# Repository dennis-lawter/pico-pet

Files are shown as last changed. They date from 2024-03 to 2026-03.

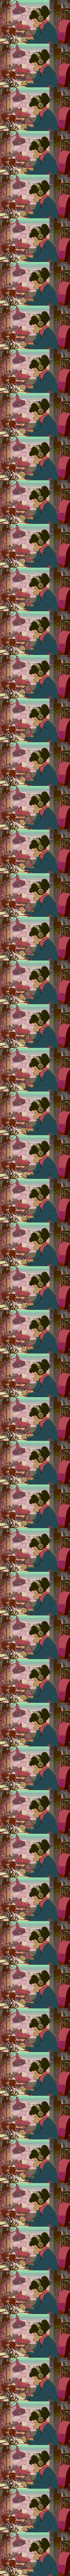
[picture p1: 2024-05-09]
embedded/assets/sprite_png/lofi.png

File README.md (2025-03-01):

# Pico Pet
A virtual pet that requires the user to complete pomodoros for the health of their pet.

## Hardware
- Raspberry Pi Pico
    - [Raspberry Pi Pico](https://www.raspberrypi.com/products/raspberry-pi-pico/) for development
    - [Waveshare RP2040-Tiny](https://www.waveshare.com/rp2040-tiny.htm) for release
- [Waveshare 1.44" LCD](https://www.waveshare.com/pico-lcd-1.44.htm)
- [DS3231](https://www.amazon.com/dp/B09KPC8JZQ/)
- Any 5v to 3v3 shifter for the DS3231, [for example](https://www.amazon.com/dp/B07LG646VS/)
- Any 5v speaker or buzzer, [for example](https://www.amazon.com/dp/B07P6X9YX7/)
- Any 3v-5v vibrating motor, [for example](https://www.amazon.com/dp/B073YFR5WR)

## NVM Utilization
The NVM (Non-Volatile Memory) module included with the DS3231 provides 4KiB arranged in 512 pages of 8 bytes each.

Permanent storage must be serializable to a specified number of pages, and write to an assigned page address.

Pages are addressed from hexidecimal 0x000 to 0x1ff.

| Page Start | Page End | Module |
| --- | --- | --- |
| 000 | 000 | Header |
| 001 | 002 | Settings |
| 003 | 003 | Inventory |
| 004 | 005 | Pet |

*note: If the NVM becomes corrupted, try changing the const `NVM_SENTINEL` to force a header guard check failure. This will factory reset the device, and all data will be lost.*
|  | **Header** |
| --- | --- |
| 0 | if set to the `NVM_SENTINEL` value, then the EEPROM is assumed to contain a valid savefile |
| 1 |  |
| 2 |  |
| 3 |  |
| 4 |  |
| 5 |  |
| 6 |  |
| 7 |  |

|  | **Settings Page 1** | min | max |
| --- | --- | --- | --- |
| 0 | User brightness | 0 | 15 |
| 1 | User volume | 0 | 4 |
| 2 | *nyi* Vibration enabled | 0 | 1 |
| 3 | *nyi* 12hr clock enabled | 0 | 1 |
| 4 | *nyi* minutes before device sleeps | 1 | 90 |
| 5 |  |  |  |
| 6 |  |  |  |
| 7 |  |  |  |

|  | **Settings Page 2** | min | max |
| --- | --- | --- | --- |
| 0 | Pomodoro length in minutes | 1 | 90 |
| 1 | Short break length in minutes | 1 | 90 |
| 2 | Long break length in minutes | 1 | 90 |
| 3 | Cycles, aka number of pomodoros before a long rest | 1 | 9 |
| 4 | Pet feeding deadline hr | 0 | 23 |
| 5 | Pet feeding deadline min | 0 | 59 |
| 6 |  |  |  |
| 7 |  |  |  |

|  | **Inventory** | min | max |
| --- | --- | --- | --- |
| 0 | Tomatoes | 0 | 99 |
| 1 | Raspberries | 0 | 9 |
| 2 | Lower byte of juice value |  |  |
| 3 | Higher byte of juice value |  |  |
| 4 |  |  |  |
| 5 |  |  |  |
| 6 |  |  |  |
| 7 |  |  |  |

Max juice is 9999ml as a u16

|  | **Pet Page 1** |
| --- | --- |
| 0 | Birth Day |
| 1 | Birth Month |
| 2 | Birth Year |
| 3 |  |
| 4 |  |
| 5 |  |
| 6 |  |
| 7 |  |

|  | **Pet Page 2** |
| --- | --- |
| 0 | Current HP |
| 1 | Sickness |
| 2 | Daily Hunger |
| 3 | Last Fed Day |
| 4 | Last Fed Month |
| 5 | Last Fed Year |
| 6 |  |
| 7 |  |

Max HP = Daily Hunger + 4

Last Fed Year is probably excessive,
but it'd be a weird bug if someone started the pet up after exactly 1 year,
and their pet showed no signs of missed days of hunger...

## Pin Out For Raspberry Pico

```mermaid
graph LR
    subgraph RP2040
        Pin1
        Pin2
        %%Pin3[GND]
        Pin4
        Pin5
        Pin6
        Pin7
        %%Pin8[GND]
        Pin9
        %%Pin10
        Pin11
        Pin12
        %%Pin13[GND]
        Pin14
        Pin15
        Pin16
        Pin17
        %%Pin18[GND]
        %%Pin19
        Pin20
        %%Pin21
        Pin22
        %%Pin23[GND]
        %%Pin24
        %%Pin25
        %%Pin26
        %%Pin27
        %%Pin28[GND]
        %%Pin29
        %%Pin30
        %%Pin31
        %%Pin32
        %%Pin33[GND]
        %%Pin34
        %%Pin35
        %%Pin36[3V3_OUT]
        %%Pin37[3V3_EN]
        %%Pin38[GND]
        %%Pin39[VSYS]
        %%Pin40[VBUS]
    end

    subgraph RTC_NVM
        RTC_SDA
        RTC_SCL
        RTC_SQW
    end
    Pin1[Pin1 I2C0_SDA] --> RTC_SDA
    Pin2[Pin2 I2C0_SCL] --> RTC_SCL
    Pin7[Pin7 GP5] --> RTC_SQW

    subgraph BUZZER
        SPEAKER
    end
    Pin6[Pin6 PWM_A2] --> SPEAKER

    subgraph VIBRATION
        MOTOR
    end
    Pin9[Pin9 GP6] --> MOTOR

    subgraph LCD
        LCD_KEY2
        LCD_KEY3
        LCD_DC
        LCD_CS
        LCD_CLK
        LCD_DIN
        LCD_RST
        LCD_BL
        LCD_KEY0
        LCD_KEY1
    end
    Pin4[Pin4 GP2] --> LCD_KEY2
    Pin5[Pin5 GP3] --> LCD_KEY3
    Pin11[Pin11 GP8] --> LCD_DC
    Pin12[Pin12 SPI1_CSn] --> LCD_CS
    Pin14[Pin14 SPI1_SCK] --> LCD_CLK
    Pin15[Pin15 SPI1_TX] --> LCD_DIN
    Pin16[Pin16 SPI1_RX] --> LCD_RST
    Pin17[Pin17 PWM_B6] --> LCD_BL
    Pin20[Pin20 GP15] --> LCD_KEY0
    Pin22[Pin22 GP17] --> LCD_KEY1
```

## Pinout for Waveshare RP2040-Tiny
```mermaid
graph LR
    subgraph RP2040-Tiny
        TinyPin0
        TinyPin1
        TinyPin2
        TinyPin3
        TinyPin4
        TinyPin5
        TinyPin6
        %%TinyPin7
        TinyPin8
        TinyPin9
        TinyPin10
        TinyPin11
        TinyPin12
        TinyPin13
        %%TinyPin14
        TinyPin15
        %%TinyPin16
        %%TinyPin17
        %%TinyPin18
        TinyPin19
        %%TinyPin20
        %%TinyPin21[3V3]
        %%TinyPin22[GND]
        %%TinyPin23[5V]
    end

    subgraph RTC_NVM
        RTC_SDA
        RTC_SCL
        RTC_SQW
    end
    TinyPin0[TinyPin0 I2C0_SDA] --> RTC_SDA
    TinyPin1[TinyPin1 I2C0_SCL] --> RTC_SCL
    TinyPin5[TinyPin5 GP5] --> RTC_SQW

    subgraph BUZZER
        SPEAKER
    end
    TinyPin4[TinyPin4 PWM_A2] --> SPEAKER

    subgraph VIBRATION
        MOTOR
    end
    TinyPin6[TinyPin6 GP6] --> MOTOR

    subgraph LCD
        LCD_KEY2
        LCD_KEY3
        LCD_DC
        LCD_CS
        LCD_CLK
        LCD_DIN
        LCD_RST
        LCD_BL
        LCD_KEY0
        LCD_KEY1
    end
    TinyPin2[TinyPin2 GP2] --> LCD_KEY2
    TinyPin3[TinyPin3 GP3] --> LCD_KEY3
    TinyPin8[TinyPin8 GP8] --> LCD_DC
    TinyPin9[TinyPin9 SPI1_CSn] --> LCD_CS
    TinyPin10[TinyPin10 SPI1_SCK] --> LCD_CLK
    TinyPin11[TinyPin11 SPI1_TX] --> LCD_DIN
    TinyPin12[TinyPin12 SPI1_RX] --> LCD_RST
    TinyPin13[TinyPin13 PWM_B6] --> LCD_BL
    TinyPin15[TinyPin15 GP15] --> LCD_KEY0
    TinyPin19[TinyPin19 GP29] --> LCD_KEY1
```

## Development Breakboard Build
Below are my recommendations for how to build the development board.

### Shopping List
All amazon links are tracking free and affiliate free; feel free to source these where you wish, but compatability is not guaranteed for other similar products.
The current iteration of the software is absolutely tied to the LCD module below, as well as the combination DS3231 & AT24C32 board.
Theoretically any RTC and NVM module could replace the aformentioned, but the I2C addresses have been set to match the product below.
Additionally, any ST7735S driven 128x128 display could be adapted. All four buttons provided on the waveshare LCD hat are used as well.
- Components
    - Expansion Board https://www.amazon.com/dp/B08X6FPRYF/
    - Breakout Board https://www.amazon.com/dp/B0B982B9HV/
    - Breadboard https://www.amazon.com/dp/B07VFFXPH3/
    - LCD Module https://www.amazon.com/dp/B0957NJP97/
    - Raspberry Pico w/ presoldered headers https://www.amazon.com/dp/B08X7HN2VG/
    - RTC Board https://www.amazon.com/dp/B09KPC8JZQ/
    - Vibrating Motor https://www.amazon.com/dp/B073YFR5WR/
    - Piezo Buzzer https://www.amazon.com/dp/B07P6X9YX7/
- Tools/Resources
    - 22 AWG solid hookup wire https://www.amazon.com/dp/B07TX6BX47/
    - 22 AWG wire stripper https://www.amazon.com/dp/B06X9875Z7/
    - CR2032 battery https://www.amazon.com/dp/B071D4DKTZ/
    - Command strip https://www.amazon.com/dp/B07P32RHQ4/

### Assembly
1. Socket the Raspberry Pico into center of the Expansion Board.
2. Socket the LCD Module into the left slot of the Expansion Board.
3. Using a command strip, attach the breadboard to the flat side of the breakout board.
    - The 1A point of the breadboard should be in the top left, near where the word VBUS is printed on the back of the breakout board.
    - While many breadboards do come with stickers, there is often no solid insulating layer for the conductive rails, and the breakout board has sharp solder points that can stab through this thin soft layer. Whatever you do, I recommend insulating these two boards or you will risk a short...
4. Connect the breakout terminal VSYS and tie point 1A on the breadboard, preferably using a red wire.
    - I recommend running this wire over the top of the board rather than the side as it would be natural to do, because there will be essentially no space between the Raspberry Pico and this specific Breakout Board when they are eventually mated.
5. Connect the breakout terminal GND (the one adjacent to VSYS) and tie point 2A on the breadboard, preferably using a black wire.
    - Again, I recommend running this wire over the top of the board.
6. Connect the data lines to the breadboard, this time allowing the wires to wrap around the side of the board (recommended colors in parenthesis):
    - GP0 to J1 (green)
    - GP1 to J2 (white)
    - GP4 to J5 (yellow)
    - GP5 to J6 (blue)
    - GP6 to J7 (green)
7. Connect new lines on the breadboard for the RTC module:
    - C2 to C3 (black)
    - D1 to D4 (red)
    - H1 to B5 (green)
    - H2 to B6 (white)
    - H6 to B7 (blue) (I recommend routing this cable up then following the other 2 data lines)
8. Connect new lines on the breadboard for the piezo buzzer:
    - G5 to F17 (orange)
    - E2 to G13 (black) (I recommend routing this along the top side, then down the gap I left in the I column)
9. Connect new lines on the breadboard for the vibration motor:
    - G7 to K16 (green)
    - F13 to F15 (black)
10. Stick the vibration motor onto the bottom of the breadboard.
11. Attach the vibration motor wires (letting the wires lay to the right):
    - red wire to G16
    - blue wire to G15
12. Place the piezo buzzer onto pins J17 and J13 (placement will secure the vibration motor wires)
13. Insert a CR2032 battery into the RTC module.
14. Place the RTC module onto pins A3, A4, A5, A6, A7, and A8.
15. Finally, socket the breakout board onto the right slot of the Expansion Board.

### Development Environment Setup
#### NixOS
I recommend running the following to open the VSCodium development environment:
```bash
nix develop --command codium .
```

You can of course just use whatever text editor you like, and simply enter the flake in a terminal with:
```bash
nix develop
```

#### Other Linux Distros
You'll need Rust installed and set to nightly-2023-11-16. Other versions may not be supported. You will likely also need udev to detect the raspberry pico. To use the makefile, you'll also want gnu make. You can review the `flake.nix` and attempt to reproduce it in your own OS.

### First Time Setup
Your first time opening this repo, you'll need to setup the dependencies and enable the thumbv6m-none-eabi target. This has been automated for you:
```bash
make init
```

### Running The Code
The build process performs a number of actions. The sprites will be converted from PNG files to raw binary files containing RGB332 data. Fonts will be converted from PNG files to binary files containg black&white data. The custom PEAT audio files will be converted from plaintext files to the binary custom BEAT format. With all assets converted, the project will finally build and attempt to upload.

All of this is as simple as invoking:
```bash
make run
```

## Attributions
Placeholder artwork (lofi.png) copyright belongs to Juan Pablo Machado.

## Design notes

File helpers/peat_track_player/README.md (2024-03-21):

# PEAT File Format
**PEAT** stands for Plaintext Embedded Audio Track.

## Purpose
The purpose of this file is to encode a track played on a single channel with single notes played in sequence.
These files are able to encode audio in a very small format for embedded hardware.

## Driver
The audio driver supports 1,256 notes per minute (NPM).
Files may compress their notes significantly by using an integer note per minute divisor (NPMD).
NPMD must be between 1 and 255.

## Example File
For an example PEAT file, this is the classic Take Me Out To The Ball Game.
- The composition is in C Major.
- The time signature is in 3/4.
- With an NPMD of 2, the hardware plays 628 notes per minute.
- Each note, in this PEAT file, is representative of a 16th note.
- To encode a fully voiced quarter note with these settings, you could do: `C4 . . .`.
- Each note is purposefully ended with a 16th note rest.
- Ending notes with a single note of rest is useful when the song has repeated notes.
- Repeated notes will sustain; later in this song there are repeated notes.
- While those notes could have been separated with 16th note rests, I decided to place a rest after every note.
- This was not the only solution to the problem, feel free to experiment.

| File | Explanation |
| --- | --- |
| `PEAT 1` | *REQUIRED* Version identifier. |
| `NPMD 2` | *REQUIRED* NPMD signifier, must be 1-255. |
| `Take Me Out To The Ball Game` | *REQUIRED* Song title, only displayed in PEAT player. |
|  | *REQUIRED* Header ends with a blank line. |
| `C4  . . . . . . _` | Play a C4 for 7 notes, then rest for 1 note. |
| `C5  . . _` | Play a C5 for 3 notes, then rest for 1 note. |
| `A4  . . _` | The period is a "sustain" indicator. |
| `G4  . . _` | Without the rest, the notes would transition with no interruption. |
| `F4  . . _` | On the embedded hardware, there should be no interruption between these 3 F4 notes |
| `G4  . . . . . . . . . . _` | This G4 plays for an entire "measure" by lasting 15 notes + a rest |

## Important notes
The notes provided must lie between C4 and C7.

The voicing is always a square wave.

You may use the following to represent a C#4 note:
- `C#4`
- `Cs4`
- `Db4`

You may use `.` to "sustain" a note for an additional note.

The `_` note represents a rest.

Notes must be separated by at least one character whitespace(spaces, tabs, newlines).

There are no chords; the hardware can play at most one note at any given time.

Without a rest, there is no distinction between repeated notes.

Repeated notes are identical to a sustain.

That is to say, that these are all identical ways to represent the same wave format:
- `C4 C4 C4 C4`
- `C4 . . .`
- `C4 . C4 .`

# BEAT File Format
The purpose of a **PEAT** file is to compile into a **BEAT** (Binary Embedded Audio Track) file.

The first byte of a BEAT file is the NPMD, and the byte must be between `0x01` and `0xFF`.

Every byte after that represents the song.

A4 (440hz) has been chosen as the byte `0x80`.

Every half-step up from A4 is an increase of that base byte by 1.

Every half-step down from A4 is a decrease of that base byte by 1.

The byte `0x00` represents a rest.

There is no idea of "sustain", instead repeated notes are assumed to be a continued note.

The following is an example BEAT file, represented in hex, from the previous snippet of Take Me Out To The Ball Game.

```beat
02 77 77 77 77 77 77 77
00 83 83 83 00 80 80 80
00 7E 7E 7E 00 7C 7C 7C
00 7E 7E 7E 7E 7E 7E 7E
00
```

Here, the first byte is `0x02` representing the NPMD.

Then, seven `0x77` bytes and a `0x00` byte follow, representing the above `C4 . . . . . . _`

The song continues from there, each byte representing the note from the PEAT file.

It's worth noting that because of the single byte at the beginning of the file,
and our typical conventions of music revolving around groups of 4 notes,
it is very common that a file will be an odd number of bytes.

The entire Take Me Out To The Ball Game BEAT file is 397 bytes,
including the 12 continuous rests at the end used for resting before the track loops in another application.

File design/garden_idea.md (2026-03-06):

# Town concept
Pets live in a 7x7 garden

┌───┬───┬───┬───┬───┬───┬───┐
│   │   │   │   │   │   │   │
├───┼───┼───┼───┼───┼───┼───┤
│   │   │   │   │   │   │   │
├───┼───┼───┼───┼───┼───┼───┤
│   │   │   │   │   │   │   │
├───┼───┼───┼───┼───┼───┼───┤
│   │   │   │ H │   │   │   │
├───┼───┼───┼───┼───┼───┼───┤
│   │   │   │   │   │   │   │
├───┼───┼───┼───┼───┼───┼───┤
│   │   │   │   │   │   │   │
├───┼───┼───┼───┼───┼───┼───┤
│   │   │   │   │   │   │   │
└───┴───┴───┴───┴───┴───┴───┘

Every day you should water a tile.
Whichever tile is the best (or latest if tied) watered will spawn a new pet.

## End of week
Every end of the week, there's an alert to view your report card.
If the pet sleeps without showing the report card,
reduce happiness by 1 for all pets,
then do the check.

In the report card:
You'll see total pomos, breaks, etc.
You'll see the watering results.

Check if any pets are older than their expected lifespan.
Kill off the oldest pet who is past their prime.
Show the user which one died.

Check if any pets are at 0 happiness.
If so, they die.

Now, if the user got at least 75% of their pomos compared to their expected...
And if the 20 pet limit is not currently met...
Sort all the plots based on water level.
Sub-sort them based on most recent watering.
At this best watered spot, spawn a new pet.

# What stats does a pet have?
Happiness: 0-16 4b
X: 0-7 3b
Y: 0-7 3b
Age (days): 0-255 8b

# What stats does the town have?
Hunger (calculated)
Hunger rate (calculated)
Expected pomos for the week: 0-255 8b
DateTime of last feeding u32
Hunger at last feeding u32?
Currently stored food: 0-65,535 u16
First day of week: 0-7 3b
Days left in tutorial mode: 0-16 4b
DateTime of last save u32

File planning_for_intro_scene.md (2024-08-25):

fade in from black to white

# System Setup
Before we begin, let's adjust a few things. If you need to go back to a previous page, hold the BACK button.

`brightness entry`

`volume entry`

`vibration entry`

`Confirm`

# Welcome
<!-- Introduce pet -->

# Setup
Please enter today's date

`date selector`

`Confirm`

# Setup
Please enter the current time

`AM/PM selector`

`time selector`

`Confirm`

# Pet Nutrition
<!-- Explain pet nutrition -->

# Setup
What would be a good time to feed your pet? If you fail to feed the pet by the deadline, your pet may get sick!

`feed time selector`

`Confirm`

# About Pomodoro
<!-- Explain pomodoro -->

# Setup
Cycles are important for obtaining raspberries. How many cycles should a full pomodoro cycle contain?

`cycle entry`

`Confirm`

# Setup
How long would you like your work session to be? (recommended: 25m)

`pomo time entry`

`Confirm`

How long would you like your short rest to be? (recommended: 5m)

`short rest entry`

`Confirm`

How long would you like your long rest to be? (recommended: 15m)

`long rest entry`

`Confirm`

# Ready?
That wraps it up! You can change any of these settings later.

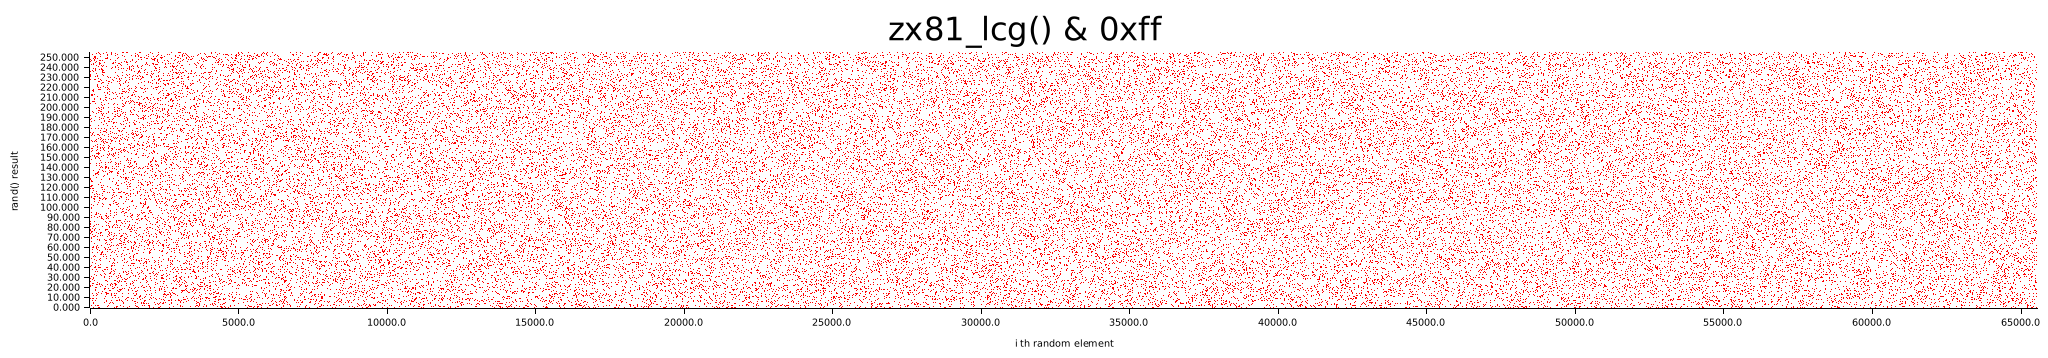
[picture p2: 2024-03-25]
helpers/rng-plotter/output.png

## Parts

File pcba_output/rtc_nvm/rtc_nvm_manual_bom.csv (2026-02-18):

Comment | Designator | Footprint | LCSC Part Number
4.7uF | C1 | 0805 | C1779
CR1225 Battery Clip | J1 |  | C20606803
5P 2.54mm Header Pins | J2 |  | C5156614
5.1k ohm | R1,R2,R3 | 0402 | C22356228
DS3231M I2C RTC | U1 | SOIC-8_3.9x4.9mm | C107410
AT24CS32 I2C NVM | U2 | SOIC-8_3.9x5.4mm | C615972

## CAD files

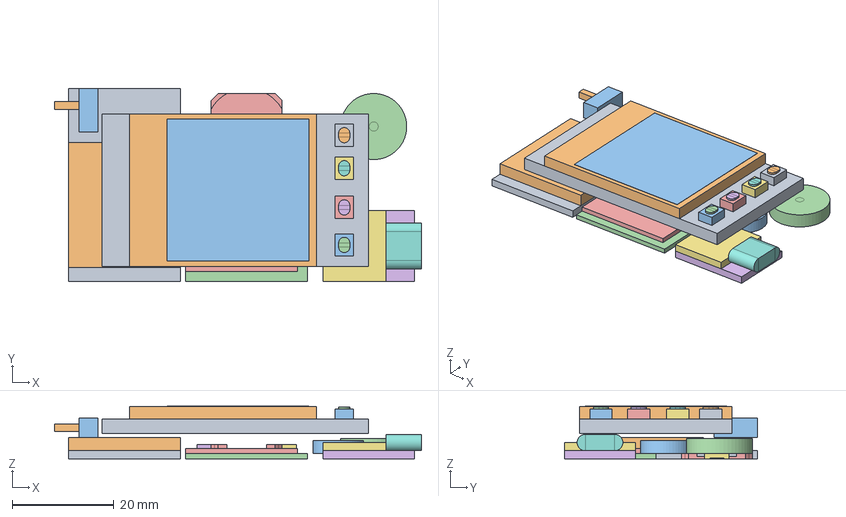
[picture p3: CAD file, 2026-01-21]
freecad/picopet.FCStd
72.2 x 38.0 x 10.4 mm
BoardAndSmds
ScreenHousing
Base
Rubber
Base001
Rubber001
Base002
Rubber002
Base003
Rubber003
Display
Board
Components
Board001
Components001
USBC
Board002
Components002
Pole

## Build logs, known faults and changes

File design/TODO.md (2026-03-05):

# Design
- TODO: list

# Hardware
## USB board
- Finalize circuit
- Upload to circuit fab and customize
- Order circuit
- Receive modules
- Solder headers to a test board
- Confirm function w/ dev board
## MCU board
- TODO: list

# Software
- TODO: list

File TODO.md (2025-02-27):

# TODO

This list is not final. It will grow and evolve.

Done items should be removed from the list.

- Misc
  - When adjusting date/time, there needs to be adjustments made to the feeding schedule
  - Warn users when adjusting date/time that feeding schedule may be affected (maybe unnecessary?)
  - Idle setting, how many minutes
  - Store the `MainScene::menu_item_selected` as a static/global for reloading the scene
  - Handle AM/PM time adjustment in settings scene
- Intro Scene
  - Introduce pet
  - Explain the pomodoro method
  - Explain how feeding works
  - Force the player to save each of the setting components
    - Possibly describe how they each work (why must we have a clock?)
  - Finalize by saving to NVM and pet greeting scene
  - Remove the current code which checks for invalid NVM then autowrites
- Stats Scene
  - Displays information about the pet:
    - Birthday (requires intro scene)
    - Age (should this go up if date changes?)
    - Current daily hunger
    - Illness if applicable
- Eating Scene
  - Opening the scene after eating today says the pet cannot eat again.
  - Upon opening the eating scene present pet's hunger
    - With no feed history (fresh start), pet hungers for 1 tomato
  - Allow the player to select how many tomatoes to feed pet
    - Pet can be fed up to its hunger
  - Inform player that all tomatoes not fed will be juiced automatically
  - Confirm button
    - Write the day to NVM
      - Pet's hunger is adjusted
      - Pet's health is adjusted
      - Tomatoes fed removed, remaining juiced
- Shop Scene
  - Spend raspberries for cosmetics
  - Cosmetics are locked behind "level" (HP)
- Pet maintenance
  - Introduce check, runs at feeding deadline
    - Must have save data for last time a day was written to NVM
- Pet rework
  - Switch from Ferris to a custom designed pet
  - Switch from lofi girl to custom animation(s)

## General Ideas
Just ideas, not committed to them
- Start
  - Pet starts the game with 5 HP.
  - Pet starts the game with 5 Max HP.
  - Pet starts the game with a renewing hunger of 1.
- Feeding
  - Entering the feeding scene, player can commit to feeding.
  - All tomatoes up to the hunger are consumed.
  - If hunger remains, pet consumes 6 juice per tomato of hunger missing.
  - Every leftover tomato becomes 5 juice.
  - Feeding must be done by the configured "eating deadline"; and a date is saved from teh last feeding.
  - Failing to eat enough causes the pet to lose 1 HP per tomato of hunger remaining.
  - Eating enough tomatoes with no juice consumed regains 1 HP.
- Pet leveling
  - Occurs during feeding, when a tomato is fed.
  - Pet will monitor the amount of juice the player has accumulated.
  - If the player has enough juice to let the pet's hunger be satisfied for 5 consecutive feedings and the pet's HP is at maximum:
    - Pet consumes +1 tomato during the feeding.
    - Pet's renewing hunger goes up by 1.
    - Pet's Max HP and HP both raise by 1.
  - If the player has not fed the pet enough and the HP drops to 0:
    - Pet is now "sick".
    - Pet's hunger immediately drops by 1 (min 1).
    - Pet's max HP drops by 1 (min 5).
    - Pet's current HP increases to 3.
    - A sick pet can only consume juice.
    - All tomatoes accumulated are juiced instead of fed whole.
    - Each 6 juice consumed regains 1 HP.
    - The player has the option to feed a sick pet a single raspberry, restoring 1 additional HP.
    - Sickness ends when the pet's HP is restored to full.
  - Need a plateau effect somehow, which detects when players have reached their healthy sustainable limit.
    - In the plateau period, pet can somehow adjust consumption to prevent leveling up.
    - Alternatively, have the level up require a consistent overproduction (a trial period).
    - Alternatively, have the user select if they would like to level up.
- Hiatus
  - A player needs the option to rest for vacations and other long breaks.
  - However, abusing the break system is not encouraged.
  - Perhaps entering the break costs 1 HP.
  - Perhaps the player must spend 1 raspberry to enter a hiatus.
  - During hiatus, the player cannot score tomatoes, juice, or raspberries.
  - The pomodoro setting could still function though, just with a warning.

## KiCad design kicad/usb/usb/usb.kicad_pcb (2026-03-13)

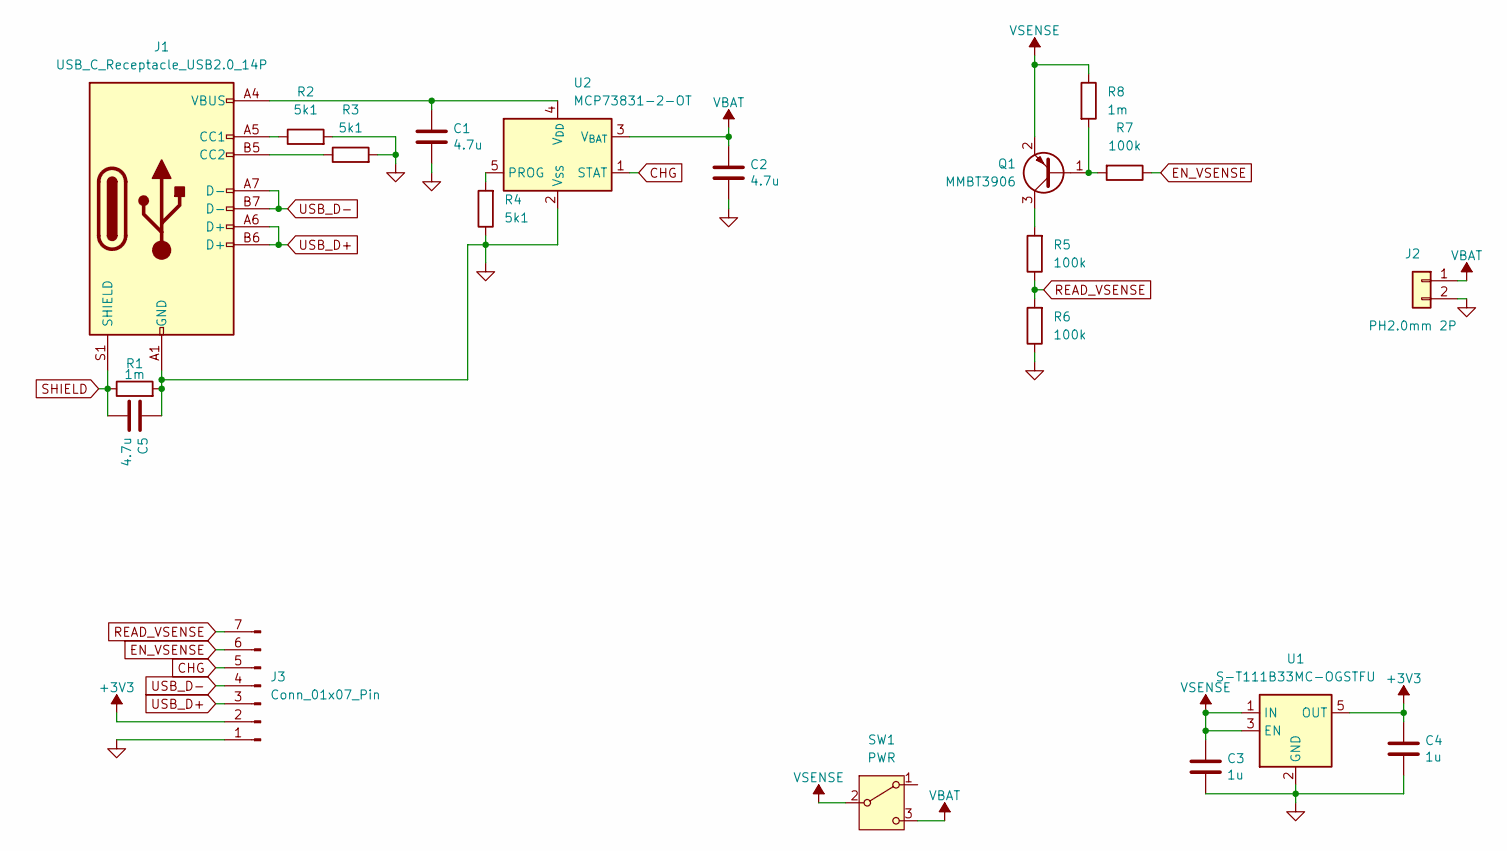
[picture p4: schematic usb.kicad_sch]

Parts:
C1, C2: 4.7u; C_0805_2012Metric; LCSC C15850
C3, C4: 1u; C_0805_2012Metric; LCSC C15850
C5: 4.7u; C_0603_1608Metric_Pad1.08x0.95mm_HandSolder; LCSC C15850
J1: USB_C_Receptacle_USB2.0_14P; USB_C_Receptacle_GCT_USB4105-xx-A_16P_TopMnt_Horizontal
J2: PH2.0mm 2P; JST_PH_S2B-PH-K_1x02_P2.00mm_Horizontal; LCSC C124375
J3: Conn_01x07_Pin; PinHeader_1x07_P2.54mm_Vertical
Q1: MMBT3906; SOT-23
R1: 1m; R_0603_1608Metric_Pad0.98x0.95mm_HandSolder
R2, R3, R4: 5k1; R_0201_0603Metric_Pad0.64x0.40mm_HandSolder
R5, R6, R7: 100k; R_0402_1005Metric_Pad0.72x0.64mm_HandSolder
R8: 1m; R_0402_1005Metric_Pad0.72x0.64mm_HandSolder
SW1: PWR; SW_Slide_SPDT_Angled_CK_OS102011MA1Q
U1: S-T111B33MC-OGSTFU; SOT-23-5
U2: MCP73831-2-OT; SOT-23-5

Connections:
+3V3: C4.1, J3.2, U1.5 (OUT)
CHG: J3.5, U2.1 (STAT)
EN_VSENSE: J3.6, R7.1
GND: C1.2, C2.2, C3.2, C4.2, C5.1, J1.A1 (GND), J1.A12 (GND), J1.B1 (GND), J1.B12 (GND), J2.2, J3.1, R1.2, R2.2, R3.2, R4.1, R6.1, U1.2 (GND), U1.4 (GND), U2.2 (V_{SS})
unnamed: J1.A5 (CC1), R2.1
unnamed: J1.B5 (CC2), R3.1
unnamed: Q1.1 (B), R7.2, R8.2
unnamed: Q1.3 (C), R5.2
unnamed: R4.2, U2.5 (PROG)
unnamed: C1.1, J1.A4 (VBUS), J1.A9 (VBUS), J1.B4 (VBUS), J1.B9 (VBUS), U2.4 (V_{DD})
READ_VSENSE: J3.7, R5.1, R6.2
SHIELD: C5.2, J1.S1 (SHIELD), R1.1
USB_D+: J1.A6 (D+), J1.B6 (D+), J3.3
USB_D-: J1.A7 (D-), J1.B7 (D-), J3.4
VBAT: C2.1, J2.1, SW1.3 (C), U2.3 (V_{BAT})
VSENSE: C3.1, Q1.2 (E), R8.1, SW1.2 (B), U1.1 (IN), U1.3 (EN)

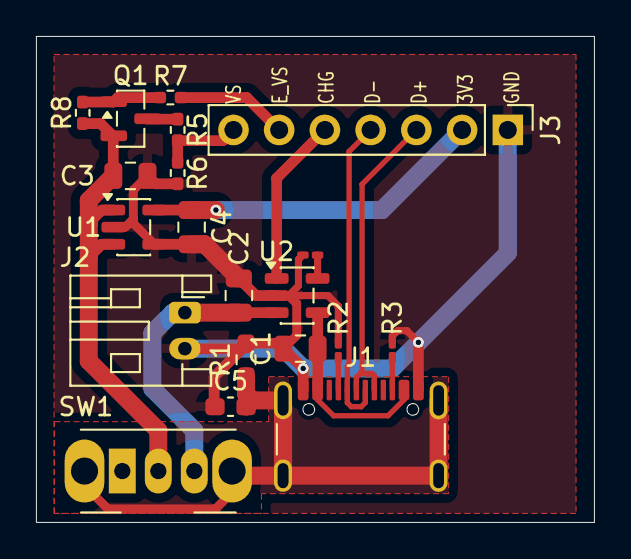
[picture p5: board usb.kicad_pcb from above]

Board: 2 copper layers, 31.0 x 27.0 mm, 20 parts (0 on the bottom side), 16 nets.

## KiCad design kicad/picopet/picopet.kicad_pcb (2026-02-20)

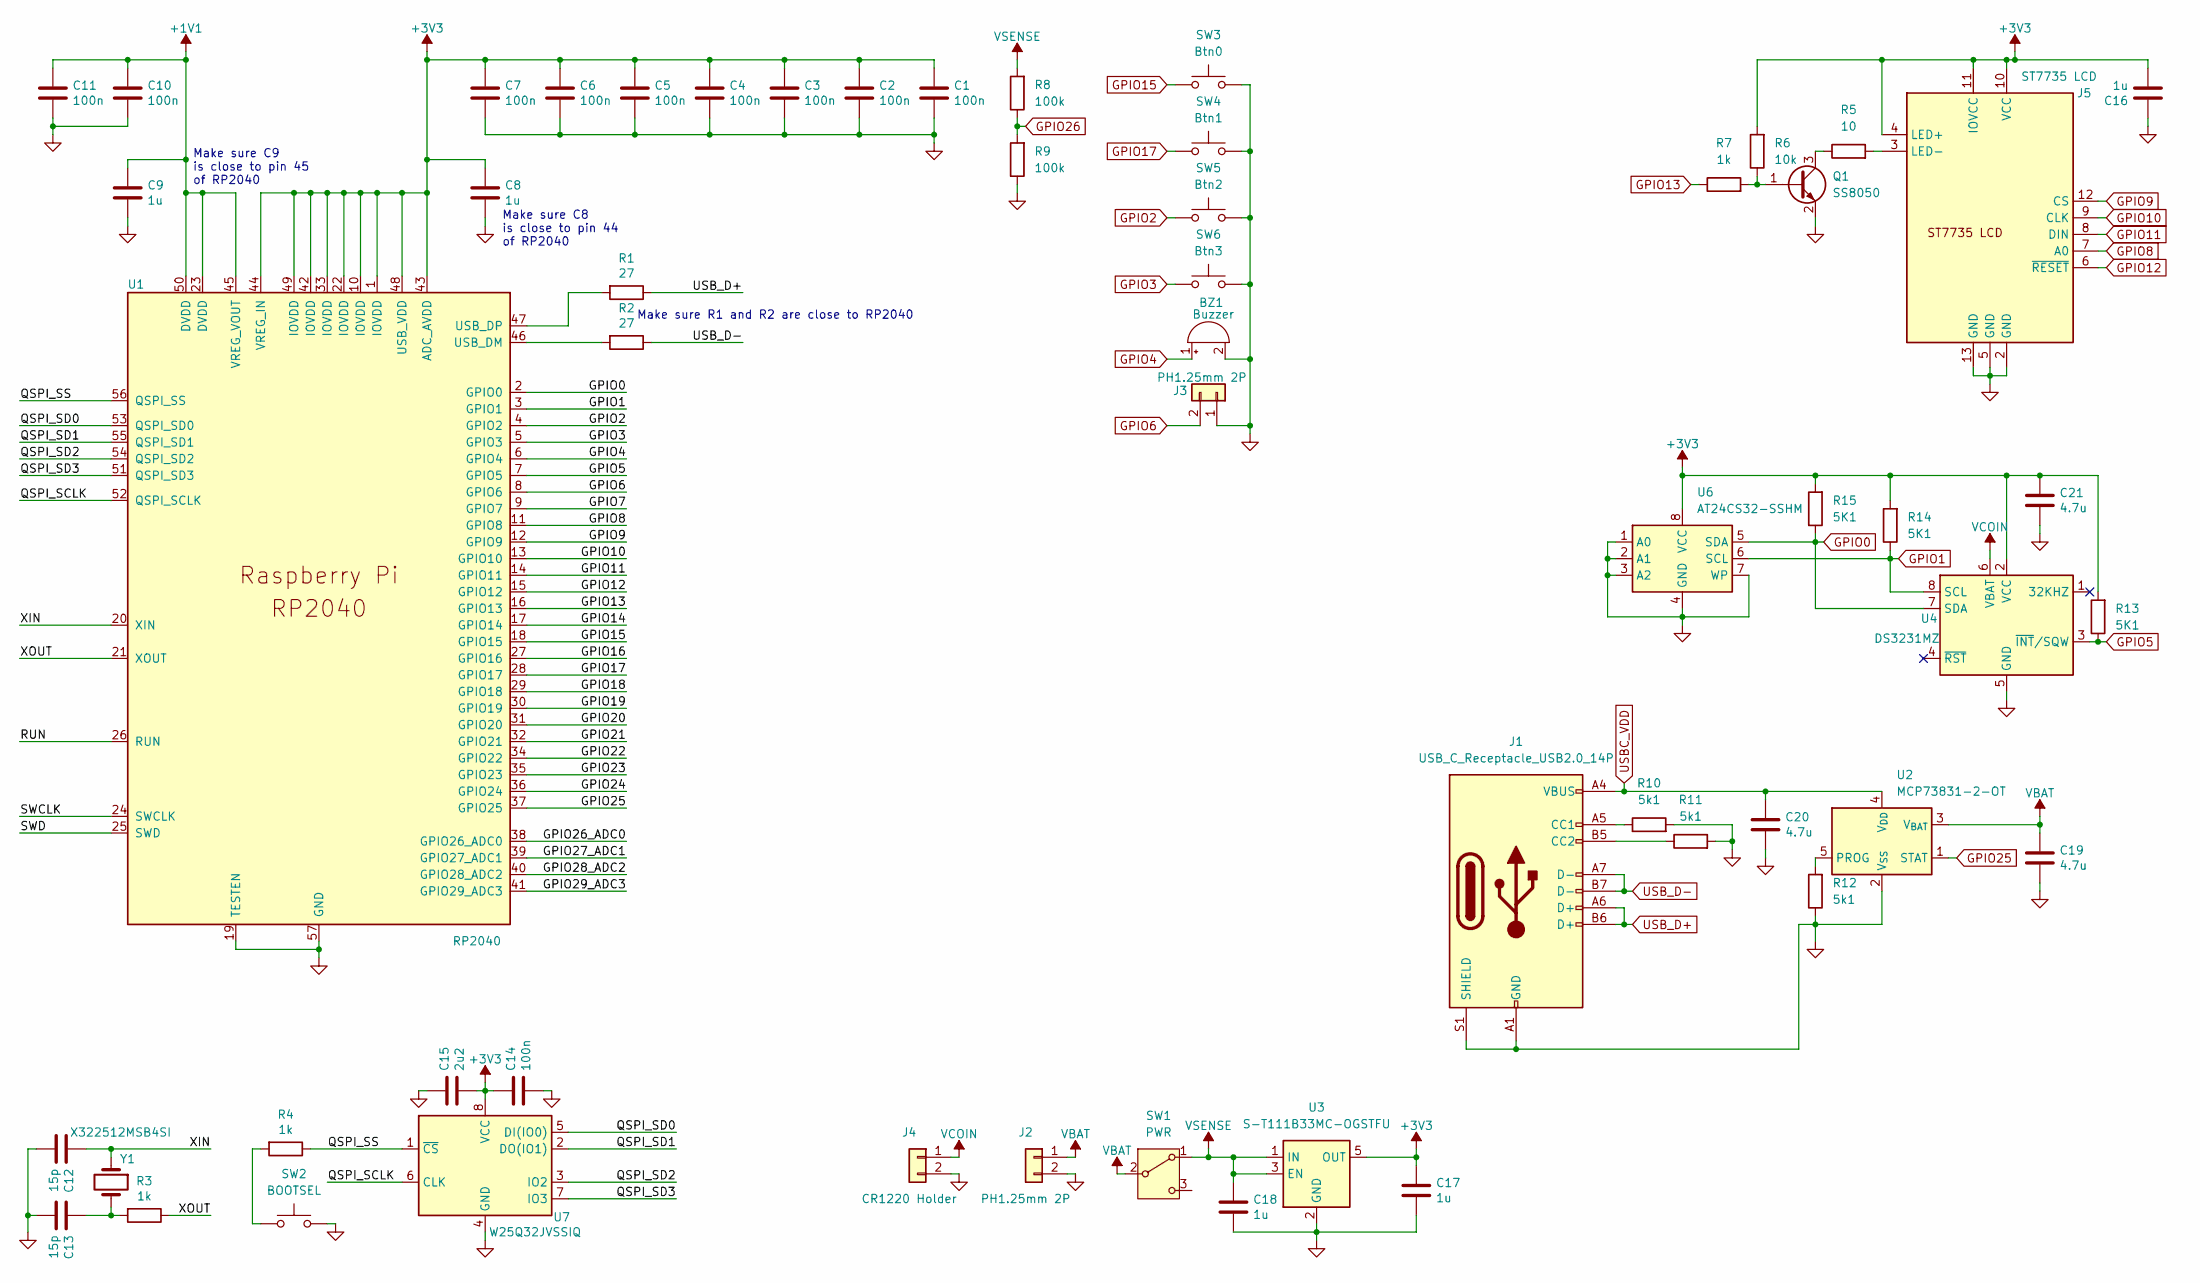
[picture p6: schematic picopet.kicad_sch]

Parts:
BZ1: Buzzer; MagneticBuzzer_Kobitone_254-EMB84Q-RO
C1, C2, C3, C4, C5, C6, C7, C10, C11, C14: 100n; C_0402_1005Metric; LCSC C126504
C8, C9: 1u; C_0402_1005Metric; LCSC C307331
C12, C13: 15p; C_0402_1005Metric; LCSC C52923
C15: 2u2; C_0402_1005Metric; LCSC C126504
C16: 1u; C_0402_1005Metric; LCSC C126504
C17, C18: 1u; C_0805_2012Metric; LCSC C15850
C19, C20, C21: 4.7u; C_0805_2012Metric; LCSC C15850
J1: USB_C_Receptacle_USB2.0_14P; USB_C_Receptacle_GCT_USB4105-xx-A_16P_TopMnt_Horizontal
J2, J3: PH1.25mm 2P; JST_GH_SM02B-GHS-TB_1x02-1MP_P1.25mm_Horizontal; LCSC C124375
J4: CR1220 Holder; BatteryHolder_LINX_BAT-HLD-012-SMT; LCSC C124375
J5: ST7735 LCD; ST7735_P0.8mm
Q1: SS8050; SOT-23
R1, R2: 27; R_0201_0603Metric; LCSC C274349
R3: 1k; R_0402_1005Metric; LCSC C11702
R4: 1k; R_0201_0603Metric; LCSC C11702
R5: 10; R_0201_0603Metric
R6: 10k; R_0201_0603Metric
R7: 1k; R_0201_0603Metric
R8, R9: 100k; R_0402_1005Metric
R10, R11, R12: 5k1; R_0201_0603Metric
R13, R14, R15: 5K1; R_0201_0603Metric
SW1: PWR; SW_Slide_SPDT_Angled_CK_OS102011MA1Q
SW2: BOOTSEL; SW_SPST_EVQP2_MiddlePushTravel_H2.5mm
SW3: Btn0; SW_SPST_EVQP2_MiddlePushTravel_H2.5mm
SW4: Btn1; SW_SPST_EVQP2_MiddlePushTravel_H2.5mm
SW5: Btn2; SW_SPST_EVQP2_MiddlePushTravel_H2.5mm
SW6: Btn3; SW_SPST_EVQP2_MiddlePushTravel_H2.5mm
U1: RP2040; QFN-56-1EP_7x7mm_P0.4mm_EP3.2x3.2mm; LCSC C2040
U2: MCP73831-2-OT; SOT-23-5
U3: S-T111B33MC-OGSTFU; SOT-23-5
U4: DS3231MZ; SOIC-8_3.9x4.9mm_P1.27mm
U6: AT24CS32-SSHM; SOIC-8_3.9x4.9mm_P1.27mm
U7: W25Q32JVSSIQ; SOIC-8_3.9x4.9mm_P1.27mm; LCSC C97521
Y1: X322512MSB4SI; Crystal_SMD_3225-4Pin_3.2x2.5mm; LCSC C110563

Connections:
+1V1: C9.1, C10.1, C11.1, U1.23 (DVDD), U1.45 (VREG_VOUT), U1.50 (DVDD)
+3V3: C1.1, C2.1, C3.1, C4.1, C5.1, C6.1, C7.1, C8.1, C14.1, C15.2, C16.2, C17.1, C21.1, J5.4 (LED+), J5.10 (VCC), J5.11 (IOVCC), R6.2, R13.2, R14.2, R15.2, U1.1 (IOVDD), U1.10 (IOVDD), U1.22 (IOVDD), U1.33 (IOVDD), U1.42 (IOVDD), U1.43 (ADC_AVDD), U1.44 (VREG_IN), U1.48 (USB_VDD), U1.49 (IOVDD), U3.5 (OUT), U4.2 (VCC), U6.8 (VCC), U7.8 (VCC)
/GPIO7: U1.9 (GPIO7)
/GPIO14: U1.17 (GPIO14)
/GPIO16: U1.27 (GPIO16)
/GPIO18: U1.29 (GPIO18)
/GPIO19: U1.30 (GPIO19)
/GPIO20: U1.31 (GPIO20)
/GPIO21: U1.32 (GPIO21)
/GPIO22: U1.34 (GPIO22)
/GPIO23: U1.35 (GPIO23)
/GPIO24: U1.36 (GPIO24)
/GPIO26_ADC0: U1.38 (GPIO26_ADC0)
/GPIO27_ADC1: U1.39 (GPIO27_ADC1)
/GPIO28_ADC2: U1.40 (GPIO28_ADC2)
/GPIO29_ADC3: U1.41 (GPIO29_ADC3)
/QSPI_SCLK: U1.52 (QSPI_SCLK), U7.6 (CLK)
/QSPI_SD0: U1.53 (QSPI_SD0), U7.5 (DI(IO0))
/QSPI_SD1: U1.55 (QSPI_SD1), U7.2 (DO(IO1))
/QSPI_SD2: U1.54 (QSPI_SD2), U7.3 (IO2)
/QSPI_SD3: U1.51 (QSPI_SD3), U7.7 (IO3)
/QSPI_SS: R4.1, U1.56 (QSPI_SS), U7.1 (~CS)
/RUN: U1.26 (RUN)
/SWCLK: U1.24 (SWCLK)
/SWD: U1.25 (SWD)
/XIN: C12.1, U1.20 (XIN), Y1.1
/XOUT: R3.1, U1.21 (XOUT)
GND: BZ1.2 (-), C1.2, C2.2, C3.2, C4.2, C5.2, C6.2, C7.2, C8.2, C9.2, C10.2, C11.2, C12.2, C13.2, C14.2, C15.1, C16.1, C17.2, C18.2, C19.2, C20.2, C21.2, J1.A1 (GND), J1.A12 (GND), J1.B1 (GND), J1.B12 (GND), J1.S1 (SHIELD), J2.2, J3.1, J4.2, J5.2 (GND), J5.5 (GND), J5.13 (GND), Q1.2 (E), R9.1, R10.2, R11.2, R12.1, SW2.2, SW3.2, SW4.2, SW5.2, SW6.2, U1.19 (TESTEN), U1.57 (GND), U2.2 (V_{SS}), U3.2 (GND), U3.4 (GND), U4.5 (GND), U6.1 (A0), U6.2 (A1), U6.3 (A2), U6.4 (GND), U6.7 (WP), U7.4 (GND)
GPIO0: R15.1, U1.2 (GPIO0), U4.7 (SDA), U6.5 (SDA)
GPIO1: R14.1, U1.3 (GPIO1), U4.8 (SCL), U6.6 (SCL)
GPIO2: SW5.1, U1.4 (GPIO2)
GPIO3: SW6.1, U1.5 (GPIO3)
GPIO4: BZ1.1 (+), U1.6 (GPIO4)
GPIO5: R13.1, U1.7 (GPIO5), U4.3 (~INT/SQW)
GPIO6: J3.2, U1.8 (GPIO6)
GPIO8: J5.7 (A0), U1.11 (GPIO8)
GPIO9: J5.12 (CS), U1.12 (GPIO9)
GPIO10: J5.9 (CLK), U1.13 (GPIO10)
GPIO11: J5.8 (DIN), U1.14 (GPIO11)
GPIO12: J5.6 (~RESET), U1.15 (GPIO12)
GPIO13: R7.1, U1.16 (GPIO13)
GPIO15: SW3.1, U1.18 (GPIO15)
GPIO17: SW4.1, U1.28 (GPIO17)
GPIO25: U1.37 (GPIO25), U2.1 (STAT)
GPIO26: R8.1, R9.2
unnamed: C13.1, R3.2, Y1.2
unnamed: J1.A5 (CC1), R10.1
unnamed: J1.B5 (CC2), R11.1
unnamed: J5.3 (LED-), R5.2
unnamed: Q1.1 (B), R6.1, R7.2
unnamed: Q1.3 (C), R5.1
unnamed: R4.2, SW2.1
unnamed: R2.2, U1.46 (USB_DM)
unnamed: R1.2, U1.47 (USB_DP)
unnamed: R12.2, U2.5 (PROG)
USBC_VDD: C20.1, J1.A4 (VBUS), J1.A9 (VBUS), J1.B4 (VBUS), J1.B9 (VBUS), U2.4 (V_{DD})
USB_D+: J1.A6 (D+), J1.B6 (D+), R1.1
USB_D-: J1.A7 (D-), J1.B7 (D-), R2.1
VBAT: C19.1, J2.1, SW1.2 (B), U2.3 (V_{BAT})
VCOIN: J4.1, U4.6 (VBAT)
VSENSE: C18.1, R8.2, SW1.1 (A), U3.1 (IN), U3.3 (EN)

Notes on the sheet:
Make sure R1 and R2 are close to RP2040
Make sure C9 is close to pin 45 of RP2040
Make sure C8 is close to pin 44 of RP2040

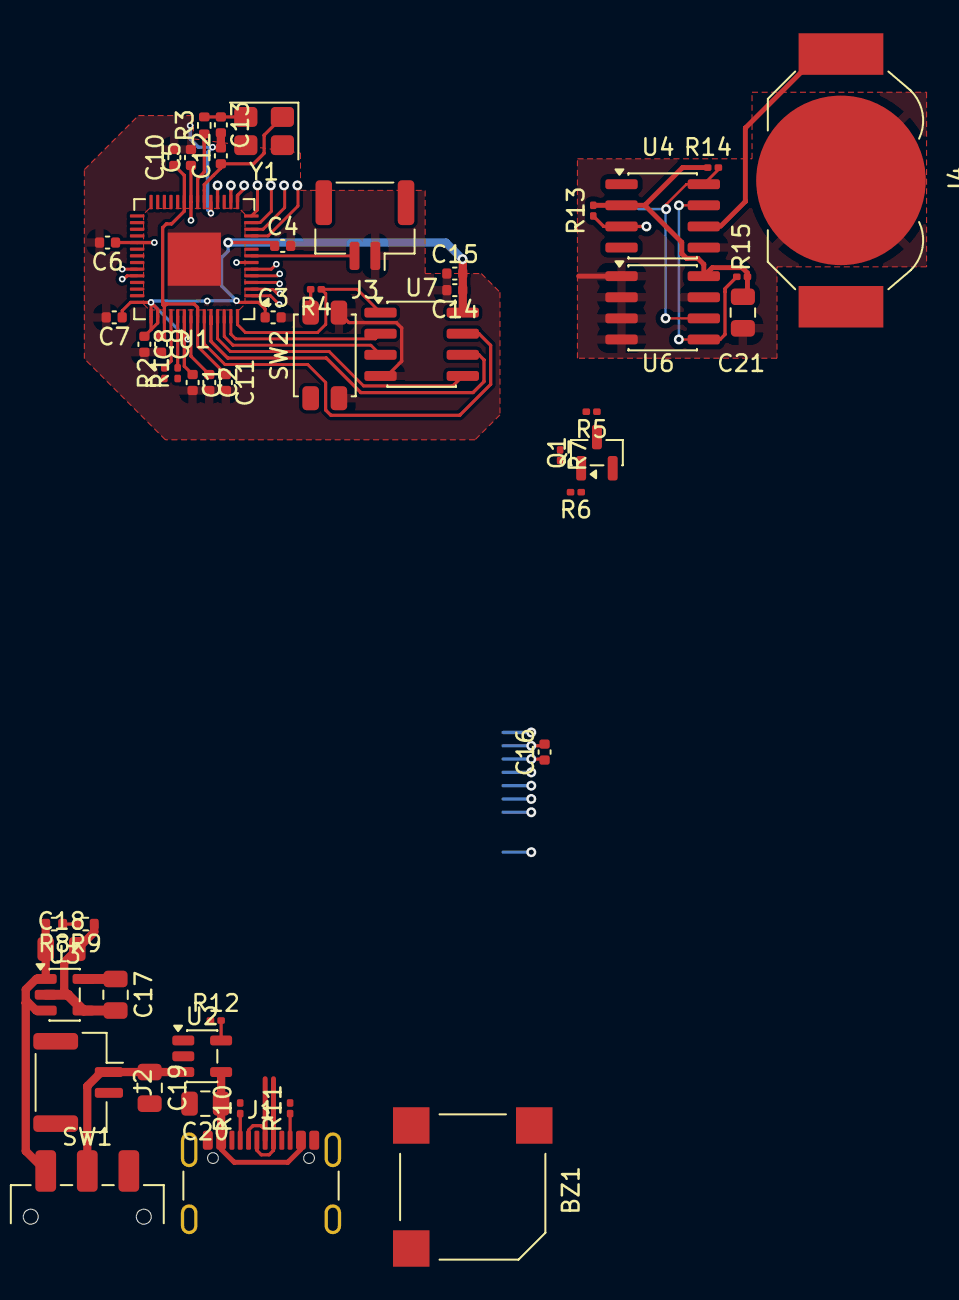
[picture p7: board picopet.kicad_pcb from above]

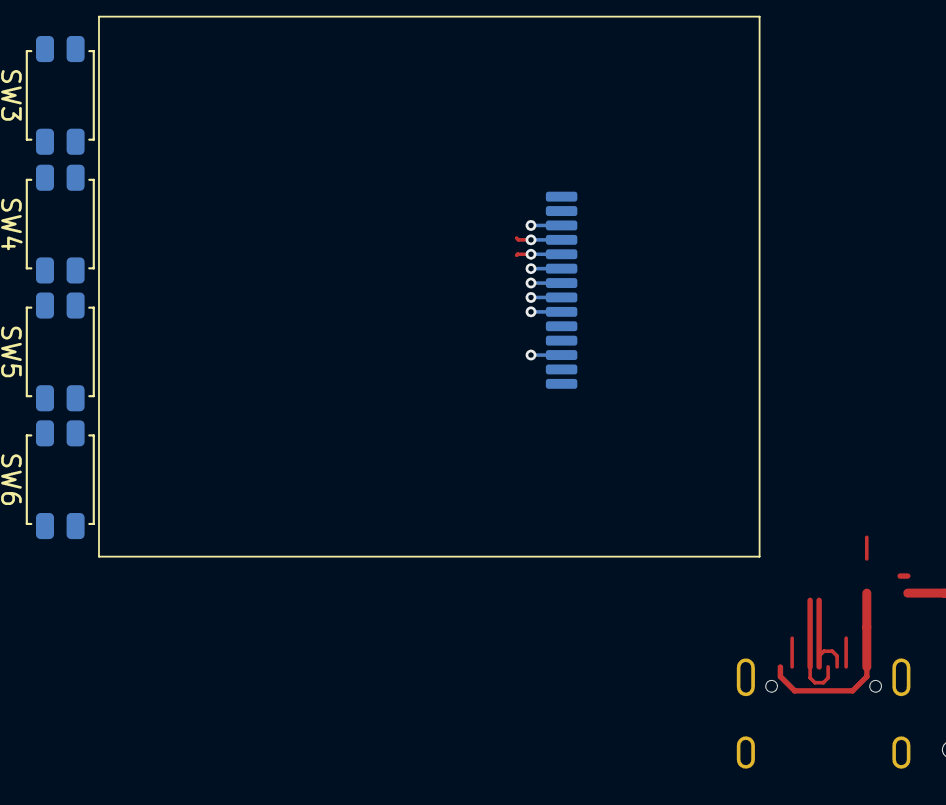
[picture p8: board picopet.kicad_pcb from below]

Board: 2 copper layers, 56 parts (5 on the bottom side), 44 nets.

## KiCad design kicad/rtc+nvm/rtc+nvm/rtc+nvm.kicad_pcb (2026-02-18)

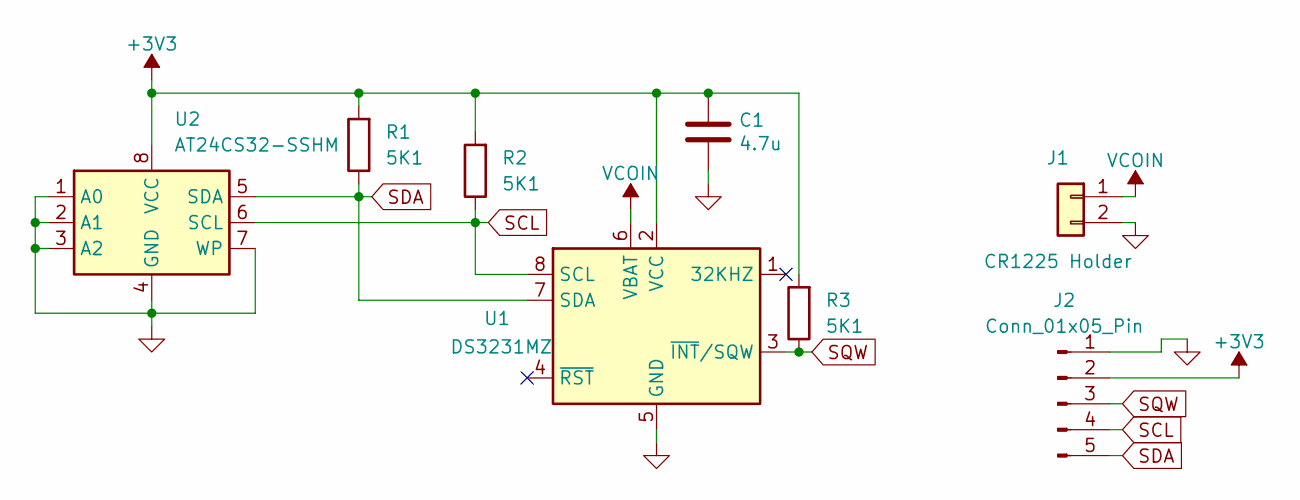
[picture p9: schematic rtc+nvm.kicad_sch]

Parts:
C1: 4.7u; C_0805_2012Metric; LCSC C15850
J1: CR1225 Holder; BatteryHolder_LINX_BAT-HLD-012-SMT; LCSC C124375
J2: Conn_01x05_Pin; PinHeader_1x05_P2.54mm_Vertical
R1, R2, R3: 5K1; R_0402_1005Metric_Pad0.72x0.64mm_HandSolder
U1: DS3231MZ; SOIC-8_3.9x4.9mm_P1.27mm
U2: AT24CS32-SSHM; SOIC-8_3.9x4.9mm_P1.27mm

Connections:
+3V3: C1.1, J2.2, R1.2, R2.2, R3.2, U1.2 (VCC), U2.8 (VCC)
GND: C1.2, J1.2, J2.1, U1.5 (GND), U2.1 (A0), U2.2 (A1), U2.3 (A2), U2.4 (GND), U2.7 (WP)
SCL: J2.4, R2.1, U1.8 (SCL), U2.6 (SCL)
SDA: J2.5, R1.1, U1.7 (SDA), U2.5 (SDA)
SQW: J2.3, R3.1, U1.3 (~INT/SQW)
VCOIN: J1.1, U1.6 (VBAT)

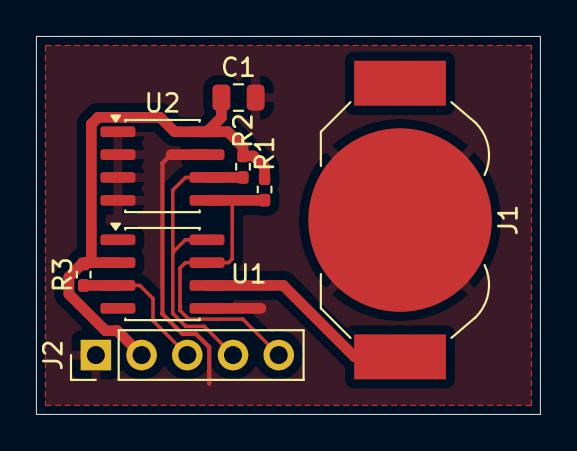
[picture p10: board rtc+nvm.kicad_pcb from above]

Board: 2 copper layers, 28.0 x 21.0 mm, 8 parts (0 on the bottom side), 6 nets.

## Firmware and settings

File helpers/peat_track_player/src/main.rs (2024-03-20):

mod audio;
mod freq;
mod model;
mod prelude;

use cursive::theme::BaseColor;
use cursive::theme::Color;
use cursive::theme::ColorStyle;
use cursive::utils::markup::StyledString;
use cursive::view::Nameable;
use cursive::view::Resizable;
use cursive::views::LinearLayout;
use cursive::views::TextView;
use cursive::Cursive;
use cursive::CursiveExt;

use clap::Parser;

use prelude::*;

fn load_model_from_filename(filename: &str) {
    let text = std::fs::read_to_string(filename).expect("Could not read file");

    let mut model = crate::model::TRACK_INSTANCE.lock().unwrap();
    model.load_text(&text);
    drop(model);
}

/// TUI audio player for the .peat format
#[derive(Parser, Debug)]
#[command(version, about, long_about = None)]
struct Args {
    /// Input file
    #[arg(value_name = "INPUT_FILE")]
    input: String,

    /// Autoplay
    #[arg(short = 'a', long = "autoplay", action = clap::ArgAction::SetTrue)]
    autoplay: bool,
}

fn main() {
    let args = Args::parse();

    if args.input.ends_with(".peat") {
        load_model_from_filename(&args.input);
    } else {
        panic!("Input must be a .peat file");
    }

    let mut siv = Cursive::default();

    build_ui(&mut siv);

    if args.autoplay {
        play_handler(&mut siv);
    }

    siv.run();
}

fn build_ui(siv: &mut cursive::Cursive) {
    siv.load_toml(include_str!("../assets/cursive.toml"))
        .unwrap();

    let split_size = SAMPLE_RATE as usize * 60 / crate::prelude::NOTES_PER_MINUTE as usize;
    let (track_title, sample_length) = {
        let model = crate::model::TRACK_INSTANCE.lock().unwrap();
        (model.title.clone(), model.samples.len() / split_size)
    };

    let progress_bar_view = cursive::views::ProgressBar::new()
        .range(0, sample_length)
        .with_label(|_, (_, _)| "".to_owned())
        .with_name("progress_bar")
        .full_width();

    let track_title_styled = StyledString::styled(
        track_title.clone(),
        ColorStyle::new(
            Color::Dark(BaseColor::White),
            Color::Light(BaseColor::Black),
        ),
    );

    let track_title_view = TextView::new(track_title_styled).center();

    let help_view = TextView::new("[SPACE] to toggle play/pause    [Q] to quit");

    let layout = LinearLayout::vertical()
        .child(track_title_view)
        .child(progress_bar_view)
        .child(help_view);

    let dialog = cursive::views::Dialog::around(layout).title("PEAT AUDIO PLAYER");
    siv.add_layer(dialog);

    siv.add_global_callback('q', |s| {
        s.quit();
    });
    siv.add_global_callback(' ', toggle_handler);
}

fn play_handler(siv: &mut cursive::Cursive) {
    let mut model = crate::model::TRACK_INSTANCE.lock().unwrap();
    if !model.playing {
        model.playing = true;
        drop(model);
        crate::audio::play_preview(siv);
        siv.call_on_name("play_button", |button: &mut cursive::views::Button| {
            button.set_label("STOP");
        });
    }
}

fn stop_handler(siv: &mut cursive::Cursive) {
    let mut model = crate::model::TRACK_INSTANCE.lock().unwrap();
    model.playing = false;
    siv.call_on_name("play_button", |button: &mut cursive::views::Button| {
        button.set_label("PLAY");
    });
}

fn toggle_handler(siv: &mut cursive::Cursive) {
    let playing = {
        let model = crate::model::TRACK_INSTANCE.lock().unwrap();
        model.playing
    };
    if playing {
        stop_handler(siv);
    } else {
        play_handler(siv);
    }
}

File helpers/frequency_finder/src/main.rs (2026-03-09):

/// Finds the best RP2040 PWM register settings to approximate A440 notes
fn main() {
    let freq_table: Vec<(&str, f32)> = vec![
        ("C4", 261.63),
        ("Cs4", 277.18),
        ("D4", 293.66),
        ("Ds4", 311.13),
        ("E4", 329.63),
        ("F4", 349.23),
        ("Fs4", 369.99),
        ("G4", 392.0),
        ("Gs4", 415.3),
        ("A4", 440.0),
        ("As4", 466.16),
        ("B4", 493.88),
        ("C5", 523.25),
        ("Cs5", 554.37),
        ("D5", 587.33),
        ("Ds5", 622.25),
        ("E5", 659.25),
        ("F5", 698.46),
        ("Fs5", 739.99),
        ("G5", 783.99),
        ("Gs5", 830.61),
        ("A5", 880.0),
        ("As5", 932.33),
        ("B5", 987.77),
        ("C6", 1046.5),
        ("Cs6", 1108.73),
        ("D6", 1174.66),
        ("Ds6", 1244.51),
        ("E6", 1318.51),
        ("F6", 1396.91),
        ("Fs6", 1479.98),
        ("G6", 1567.98),
        ("Gs6", 1661.22),
        ("A6", 1760.0),
        ("As6", 1864.66),
        ("B6", 1975.53),
        ("C7", 2093.0),
    ];

    for &(note, freq) in &freq_table {
        let best_tuple = get_closest_setting(freq);
        println!(
            "            Self::{} => AudioRegisterConfig::new{:?},",
            note, best_tuple
        );
    }
}

fn get_closest_setting(target_frequency: f32) -> (u16, u8, u8) {
    let mut closest_frequency = std::f32::INFINITY;
    let mut best_combo = (0, 0, 0);

    for div_int in 0..=255 {
        for div_frac in 0..=15 {
            let top = (125_000_000.0
                / (target_frequency * (div_int as f32 + div_frac as f32 / 16.0)))
                - 1.0;
            if top > 65535.0 {
                continue;
            }
            let frequency = 125_000_000.0 / (top + 1.0) * (div_int as f32 + div_frac as f32 / 16.0);
            if (frequency - target_frequency).abs() < (closest_frequency - target_frequency).abs() {
                closest_frequency = frequency;
                best_combo = (top as u16, div_int, div_frac);
            }
        }
    }
    best_combo
}

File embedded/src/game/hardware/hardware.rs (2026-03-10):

use cortex_m::delay::Delay;

use cortex_m::prelude::_embedded_hal_blocking_i2c_Read;
use cortex_m::prelude::_embedded_hal_blocking_i2c_Write;
use embedded_graphics::pixelcolor::Rgb565;
use embedded_graphics::prelude::DrawTarget;
use embedded_graphics::prelude::RgbColor;
use embedded_hal::digital::v2::InputPin;
use embedded_hal::digital::v2::OutputPin;
use embedded_hal::PwmPin;
use fugit::RateExtU32;

use rp2040_hal::clocks::init_clocks_and_plls;
use rp2040_hal::clocks::Clock;
use rp2040_hal::gpio::Pins;
use rp2040_hal::pac;
use rp2040_hal::pac::PPB;
use rp2040_hal::pac::PSM;
use rp2040_hal::pio::PIOExt;
use rp2040_hal::sio::SioFifo;
use rp2040_hal::watchdog::Watchdog;
use rp2040_hal::Adc;
use rp2040_hal::Sio;
use rp2040_hal::{self};

use st7735_lcd::Orientation;
use st7735_lcd::ST7735;

use crate::game::hardware::rtc::real_time::RealTime;
use crate::game::nvm::settings::SettingType;

use super::audio::AudioFrequency;
use super::rtc;
use crate::game::hardware::rtc::RealDate;
use crate::game::hardware::rtc::RealDateTime;

pub const LCD_WIDTH: usize = 128;
pub const LCD_HEIGHT: usize = 128;

const RTC_ADDRESS: u8 = 0x68;

// For the module from Amazon
// const NVM_ADDRESS: u8 = 0x57;
// For my custom module with flipped bits, whoops
// const NVM_ADDRESS: u8 = 0b_0_1010_000;

pub const BRIGHTNESS_LUT: [u16; 16] = [
    306, 438, 626, 895, 1281, 1831, 2619, 3746, 5357, 7660, 10955, 15667, 22406, 32043, 45825,
    65535,
];
pub const VOLUME_LUT: [u16; 6] = [0, 32768 / 256, 32768 / 128, 32768 / 64, 32768 / 32, 32768];

type DisplaySdi = rp2040_hal::Spi<rp2040_hal::spi::Enabled, pac::SPI1, 8>;
type DisplayDc = rp2040_hal::gpio::Pin<
    rp2040_hal::gpio::bank0::Gpio8,
    rp2040_hal::gpio::Output<rp2040_hal::gpio::PushPull>,
>;
type DisplayRst = rp2040_hal::gpio::Pin<
    rp2040_hal::gpio::bank0::Gpio12,
    rp2040_hal::gpio::Output<rp2040_hal::gpio::PushPull>,
>;

pub type Lcd = ST7735<DisplaySdi, DisplayDc, DisplayRst>;

type LcdBlPinChannel = rp2040_hal::pwm::Channel<
    rp2040_hal::pwm::Pwm6,
    rp2040_hal::pwm::FreeRunning,
    rp2040_hal::pwm::B,
>;
type BuzzerPinChannel = rp2040_hal::pwm::Channel<
    rp2040_hal::pwm::Pwm2,
    rp2040_hal::pwm::FreeRunning,
    rp2040_hal::pwm::A,
>;
type BuzzerPwmSlice = rp2040_hal::pwm::Slice<rp2040_hal::pwm::Pwm2, rp2040_hal::pwm::FreeRunning>;

type Key0Pin = rp2040_hal::gpio::Pin<
    rp2040_hal::gpio::bank0::Gpio15,
    rp2040_hal::gpio::Input<rp2040_hal::gpio::PullUp>,
>;
type Key1Pin = rp2040_hal::gpio::Pin<
    rp2040_hal::gpio::bank0::Gpio17,
    rp2040_hal::gpio::Input<rp2040_hal::gpio::PullUp>,
>;
type Key2Pin = rp2040_hal::gpio::Pin<
    rp2040_hal::gpio::bank0::Gpio2,
    rp2040_hal::gpio::Input<rp2040_hal::gpio::PullUp>,
>;
type Key3Pin = rp2040_hal::gpio::Pin<
    rp2040_hal::gpio::bank0::Gpio3,
    rp2040_hal::gpio::Input<rp2040_hal::gpio::PullUp>,
>;
type Key5Pin = rp2040_hal::gpio::Pin<
    rp2040_hal::gpio::bank0::Gpio5,
    rp2040_hal::gpio::Input<rp2040_hal::gpio::PullUp>,
>;

type Adc0Pin = rp2040_hal::gpio::Pin<
    rp2040_hal::gpio::bank0::Gpio26,
    rp2040_hal::gpio::Input<rp2040_hal::gpio::Floating>,
>;

// type VsenseEnablePin = rp2040_hal::gpio::Pin<
//     rp2040_hal::gpio::bank0::Gpio22,
//     rp2040_hal::gpio::Output<rp2040_hal::gpio::PushPull>,
// >;

type VibePin = rp2040_hal::gpio::Pin<
    rp2040_hal::gpio::bank0::Gpio6,
    rp2040_hal::gpio::Output<rp2040_hal::gpio::PushPull>,
>;

type I2CBus = rp2040_hal::I2C<
    pac::I2C0,
    (
        rp2040_hal::gpio::Pin<
            rp2040_hal::gpio::bank0::Gpio0,
            rp2040_hal::gpio::Function<rp2040_hal::gpio::I2C>,
        >,
        rp2040_hal::gpio::Pin<
            rp2040_hal::gpio::bank0::Gpio1,
            rp2040_hal::gpio::Function<rp2040_hal::gpio::I2C>,
        >,
    ),
>;

#[allow(unused)]
pub struct HardwareComponents {
    pub display: Lcd,
    pub sys_freq: u32,
    pub backlight_channel_ptr: *mut LcdBlPinChannel,
    pub buzzer_channel_ptr: *mut BuzzerPinChannel,
    pub buzzer_pwm_slice_ptr: *mut BuzzerPwmSlice,
    pub delay: Delay,
    pub key0: Key0Pin,
    pub key1: Key1Pin,
    pub key2: Key2Pin,
    pub key3: Key3Pin,
    pub second_clock: Key5Pin,
    pub vibe: VibePin,
    pub psm_ptr: *mut PSM,
    pub ppb_ptr: *mut PPB,
    pub fifo_ptr: *mut SioFifo,
    pub i2c_bus: I2CBus,
    pub adc: Adc,
    pub vsense_pin: Adc0Pin,
    // pub vsense_enable_pin: VsenseEnablePin,
    pub nvm_addr: u8,
}
impl HardwareComponents {
    pub fn new() -> Self {
        unsafe {
            let mut pac = pac::Peripherals::take().unwrap();
            let core = pac::CorePeripherals::take().unwrap();

            let mut watchdog = Watchdog::new(pac.WATCHDOG);

            let clocks = init_clocks_and_plls(
                12_000_000,
                pac.XOSC,
                pac.CLOCKS,
                pac.PLL_SYS,
                pac.PLL_USB,
                &mut pac.RESETS,
                &mut watchdog,
            )
            .ok()
            .unwrap();

            let mut sio = Sio::new(pac.SIO);
            let pins = Pins::new(
                pac.IO_BANK0,
                pac.PADS_BANK0,
                sio.gpio_bank0,
                &mut pac.RESETS,
            );

            // Init PWMs
            let mut pwm_slices: rp2040_hal::pwm::Slices =
                rp2040_hal::pwm::Slices::new(pac.PWM, &mut pac.RESETS);

            // Configure LCD PWM slice
            let pwm6 = &mut pwm_slices.pwm6;
            pwm6.set_ph_correct();
            pwm6.set_top(65535);
            pwm6.set_div_int(1);
            pwm6.set_div_frac(0);
            pwm6.enable();

            // Configure buzzer PWM slice
            let buzzer_pwm_slice_ptr: *mut BuzzerPwmSlice =
                &mut pwm_slices.pwm2 as *mut BuzzerPwmSlice;

            // Output channel B on PWM6 to GPIO 13
            let backlight_channel_ptr = &mut pwm6.channel_b as *mut LcdBlPinChannel;
            // disable backlight ASAP to hide boot artifacts
            (*backlight_channel_ptr).output_to(pins.gpio13);
            (*backlight_channel_ptr).enable();
            (*backlight_channel_ptr).set_duty(0);

            let buzzer_channel_ptr =
                &mut (*buzzer_pwm_slice_ptr).channel_a as *mut BuzzerPinChannel;
            (*buzzer_channel_ptr).output_to(pins.gpio4);
            (*buzzer_channel_ptr).enable();
            (*buzzer_channel_ptr).set_duty(0);

            (*buzzer_pwm_slice_ptr).set_ph_correct();
            (*buzzer_pwm_slice_ptr).set_div_int(0);
            (*buzzer_pwm_slice_ptr).set_div_frac(0);
            (*buzzer_pwm_slice_ptr).set_top(0);
            (*buzzer_pwm_slice_ptr).enable();

            let key0 = pins.gpio15.into_pull_up_input();
            let key1 = pins.gpio17.into_pull_up_input();
            let key2 = pins.gpio2.into_pull_up_input();
            let key3 = pins.gpio3.into_pull_up_input();

            let second_clock = pins.gpio5.into_pull_up_input();
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

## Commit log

2023-08-25 Prototype of icon font
2023-08-29 Music example, alternate pin for key1
2023-09-12 Moved audio pin
2023-09-14 Added functionality to reset the EEPROM to 0xff
    [hardware.rs]
2024-02-23 Enabled 1hz clock
2024-02-24 Disabled 1hz strobe
2024-03-02 Ugly first pass at timer - BUG: stop advances phase
2024-03-07 Testing vibration motor
2024-03-07 Timer ending popup
2024-03-07 Added motor to readme
2024-03-18 Starting work on track editor
2024-03-19 Improving track editor tui
2024-03-19 Slimmed down track editor and swapped backend
2024-03-19 Track editor minor refactor
2024-03-19 Track editor playback cleanup
2024-03-19 Track editor affected by speed mult
2024-03-19 Cleaning up track editor state management
2024-03-20 Better use of track model
2024-03-20 Track editor read for playback
2024-03-20 Track player
2024-03-20 Sunsetting track editor in favor of player
2024-03-20 peat beat conversion works on pico
2024-03-25 Fixed top bar clock
    [main.rs]
2024-08-17 Todo update and top bar timer fix
2024-09-11 Split wiring between rp2040 boards
2025-03-18 Freecad mockup
    [picopet.FCStd]
2025-03-20 Working on kicad schematics
    [picopet.kicad_pcb, picopet.kicad_sch]
2025-12-09 Fixes for bad flake
    [picopet.FCStd]
2025-12-10 Fixed pwm issue with newer rust
    [hardware.rs]
2026-01-13 Fixed dependency issue in peat track player
2026-01-21 Removed fcbak files, added a few battery sizes to model
    [picopet.FCStd]
2026-01-21 Added 1ah battery
    [picopet.FCStd]
2026-01-29 Enabled wake from interrupt on key3 and the 1hz clock
2026-01-30 Updating schematics
    [picopet.kicad_sch]
2026-01-31 More schematic work
    [picopet.kicad_pcb, picopet.kicad_sch]
2026-02-03 Working on a PCB layout, but didn't plan the LCD well enough
    [picopet.kicad_pcb, picopet.kicad_sch]
2026-02-04 Added vsense pin and debug output in NYI scene
2026-02-05 Redesigning pcb
    [picopet.kicad_pcb, picopet.kicad_sch]
2026-02-05 Removed remaining kicad backup files
2026-02-05 Working on mcu layout
    [picopet.kicad_pcb]
2026-02-09 Considering making custom RTC module first with pcb fab
    [picopet.kicad_pcb]
2026-02-12 Separated rtc+nvm module for test fabrication
    [picopet.kicad_pcb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]
2026-02-13 Added 32-sample averaging to battery reading
2026-02-13 USB module with new mosfet for battery drain prevention
    [usb.kicad_pcb, usb.kicad_sch]
2026-02-18 Moved pcb fab outputs
    [rtc+nvm-B_Cu.gbr, rtc+nvm-B_Mask.gbr, rtc+nvm-B_Paste.gbr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]
2026-02-18 Updated fab files for rtc_nvm module
    [picopet.kicad_pcb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]
2026-02-20 Various kicad edits
    [picopet.kicad_pcb, picopet.kicad_sch, usb.kicad_pcb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]
2026-02-24 Restored wfi and interrupts on idle state
2026-03-03 Adjusted parts & traces on usb kicad
    [usb.kicad_pcb, usb.kicad_sch]
2026-03-04 Added nvm addr probe
2026-03-05 Error handling and todo cleanup
    [hardware.rs]
2026-03-06 Updating idea docs
    [usb.kicad_pcb]
2026-03-06 Added mosfet enable pin, removed alt pin 1, updated var name
2026-03-10 Added pulldown resistor, made vsense enable always on
    [usb.kicad_pcb, usb.kicad_sch]
2026-03-13 Swapped the p-channel mosfet for a pnp transistor
    [usb.kicad_pcb, usb.kicad_sch]
